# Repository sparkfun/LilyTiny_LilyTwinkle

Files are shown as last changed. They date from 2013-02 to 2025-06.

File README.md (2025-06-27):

LilyTiny / LilyTwinkle
======================

[LilyTiny / LilyTwinkle  
*LilyTiny (DEV-10899)*](https://www.sparkfun.com/products/10899) / [*LilyTwinkle (DEV-11364)*](https://www.sparkfun.com/products/11364)

LilyTiny and LilyTwinkle are ATtiny85-based development boards for eTextiles applications. Due to the small size of the board and hardware limitations of the processor, they do not have a bootloader like a conventional LilyPad Arduino compatible does. Instead, six pads are available in the center of the back side of the board, allowing it to be reprogrammed with a standard AVR ISP programmer simply by inserting male headers into the end of the programming cable and pressing them against the board.

In order to write new code for the ATtiny you will need to add support to the Arduino IDE. Please refer to the High-Low Tech group at MIT for a great tutorial on doing this: [http://hlt.media.mit.edu/?p=1695](http://hlt.media.mit.edu/?p=1695)

Repository Contents
-------------------

* **/Firmware** - Separate firmware files for the LilyTiny and the LilyTwinkle.
* **/Fritzing** - Fritzing Example wiring images
* **/Hardware** - All hardware files for both the LilyTiny *and* the LilyTwinkle (they are identical boards). For simplicity's sake, the hardware files are named *LilyTiny*.
* **/Production** - Test bed files and production panel files

Documentation
--------------

* Getting Started Tutorials
  * **[LDK Experiment 6: Microcontroller Circuits](https://learn.sparkfun.com/tutorials/ldk-experiment-6-microcontroller-circuits)**
  * **[Using the LilyPad LilyTwinkle board](https://www.sparkfun.com/tutorials/390)**
* Project Tutorials
  * **[Twinkle Zodiac Constellation](https://learn.sparkfun.com/tutorials/twinkle-zodiac-constellation)**
  * **[Night Sky Halloween Costume](https://learn.sparkfun.com/tutorials/night-sky-halloween-costume)**
  * **[Firefly Jar Assembly Guide](https://learn.sparkfun.com/tutorials/firefly-jar-assembly-guide)** 
  * **[Soft Circuits: LED Feelings Pizza](https://learn.sparkfun.com/tutorials/soft-circuits-led-feelings-pizza)**
  * **[Twinkling Trick or Treat Bag](https://learn.sparkfun.com/tutorials/twinkling-trick-or-treat-bag)**
  * **[Light Up Pennant with E-Textiles](https://learn.sparkfun.com/tutorials/light-up-pennant-with-e-textiles)**
  * **[LilyTiny Plush Monster](https://learn.sparkfun.com/tutorials/lilytiny-plush-monster)**
  * **[Twinkling Fairy Wings](https://www.sparkfun.com/tutorials/396)**
* **[Tiny AVR Programmer Hookup Guide](https://learn.sparkfun.com/tutorials/tiny-avr-programmer-hookup-guide)** - Hookup guide to reprogram an ATtiny85.
* **[Re-Programming the LilyTiny / LilyTwinkle](https://learn.sparkfun.com/tutorials/re-programming-the-lilytiny--lilytwinkle)** - Tutorial to reprogram the LilyTiny or LilyTwinkle.
* **[Quick Reference Guide for ATTiny85](https://learn.sparkfun.com/resources/96)** 

License Information
-------------------
The hardware is released under [Creative Commons ShareAlike 4.0 International](https://creativecommons.org/licenses/by-sa/4.0/).
The code is beerware; if you see me (or any other SparkFun employee) at the local, and you've found our code helpful, please buy us a round!

Distributed as-is; no warranty is given.

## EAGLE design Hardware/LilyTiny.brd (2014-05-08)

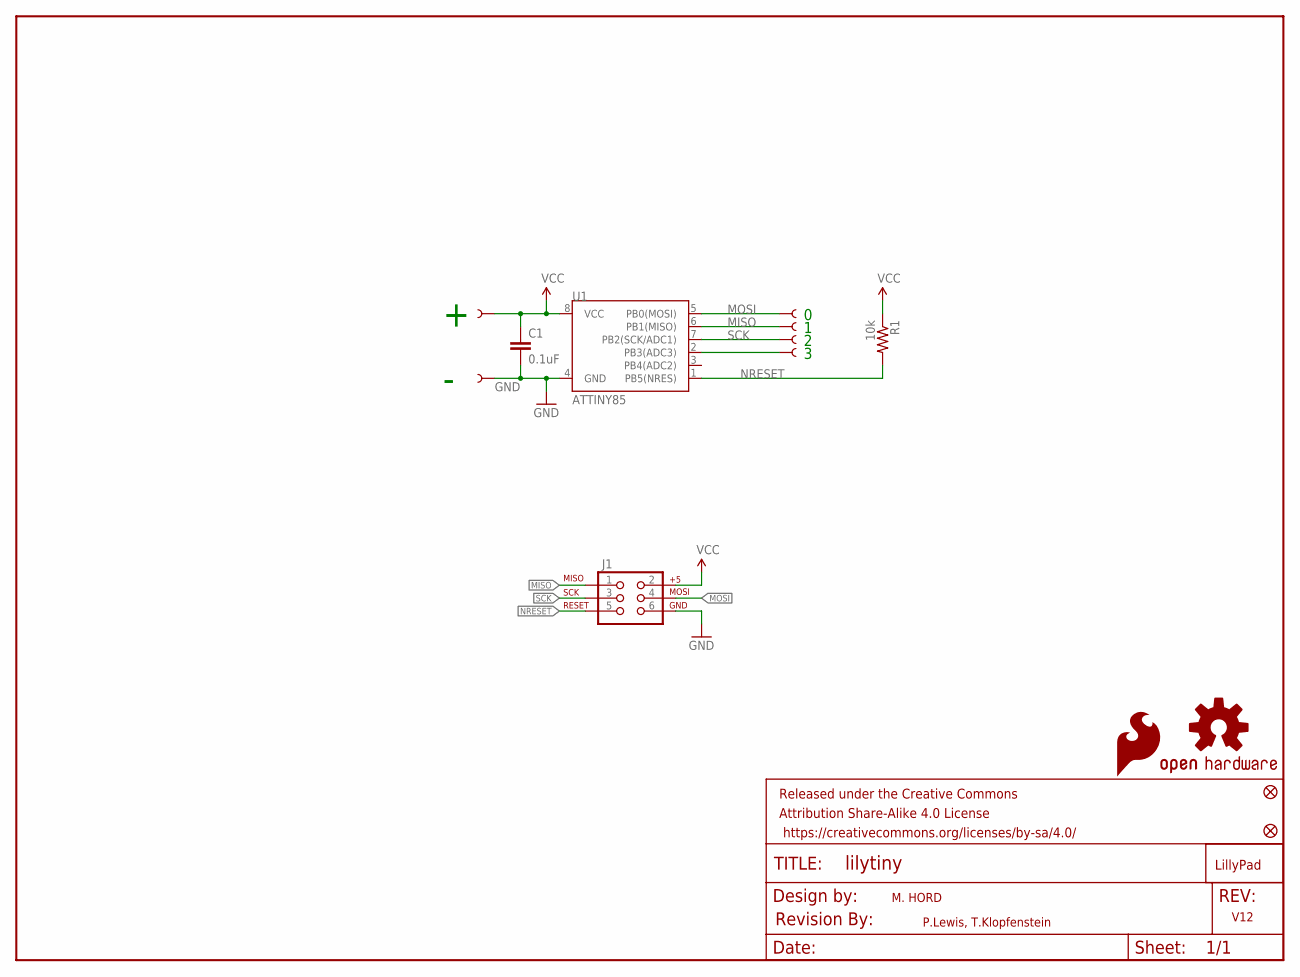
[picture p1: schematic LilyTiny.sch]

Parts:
C1: 0.1uF; 0603-CAP
FID1, FID2: FIDUCIAL1X2; FIDUCIAL-1X2
FRAME2: FRAME-LETTER; CREATIVE_COMMONS
J1: AVR_SPI_PRG_6TESTPOINTS; 2X3_TEST_POINTS
LOGO1: OSHW-LOGOS; OSHW-LOGO-S
LOGO2: SFE_LOGO_FLAME.1_INCH; SFE_LOGO_FLAME_.1
R1: 10k; 0603-RES
U1: ATTINY85; SO08-EIAJ
U$1: REVISION
U$2, U$3, U$4, U$5, U$6, U$7: SEWTAP6; PETAL-SMALL-2SIDE
U$8: LOGO-LPL; LOGO-L

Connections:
GND: C1.2, J1.6, U1.4 (GND), U$2.1
MISO: J1.1, U1.6 (PB1(MISO)), U$3.1
MOSI: J1.4, U1.5 (PB0(MOSI)), U$7.1
unnamed: U1.2 (PB3(ADC3)), U$6.1
NRESET: J1.5, R1.2, U1.1 (PB5(NRES))
SCK: J1.3, U1.7 (PB2(SCK/ADC1)), U$4.1
VCC: C1.1, J1.2, R1.1, U1.8 (VCC), U$5.1

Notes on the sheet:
M. HORD
P.Lewis, T.Klopfenstein
V12

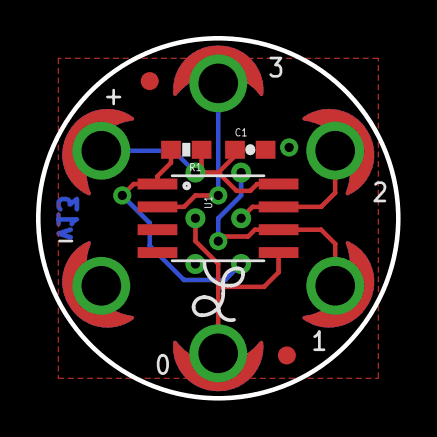
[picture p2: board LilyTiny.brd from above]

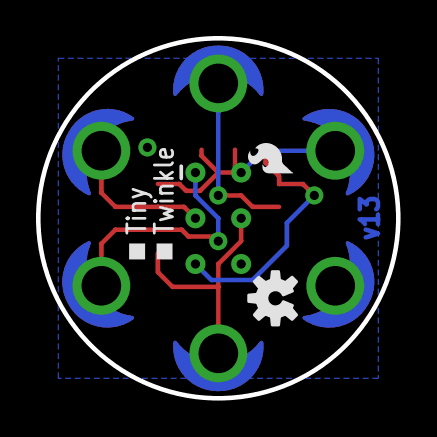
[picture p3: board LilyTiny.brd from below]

Board: 2 copper layers, 20.0 x 20.0 mm, 17 parts (3 on the bottom side), 7 nets.

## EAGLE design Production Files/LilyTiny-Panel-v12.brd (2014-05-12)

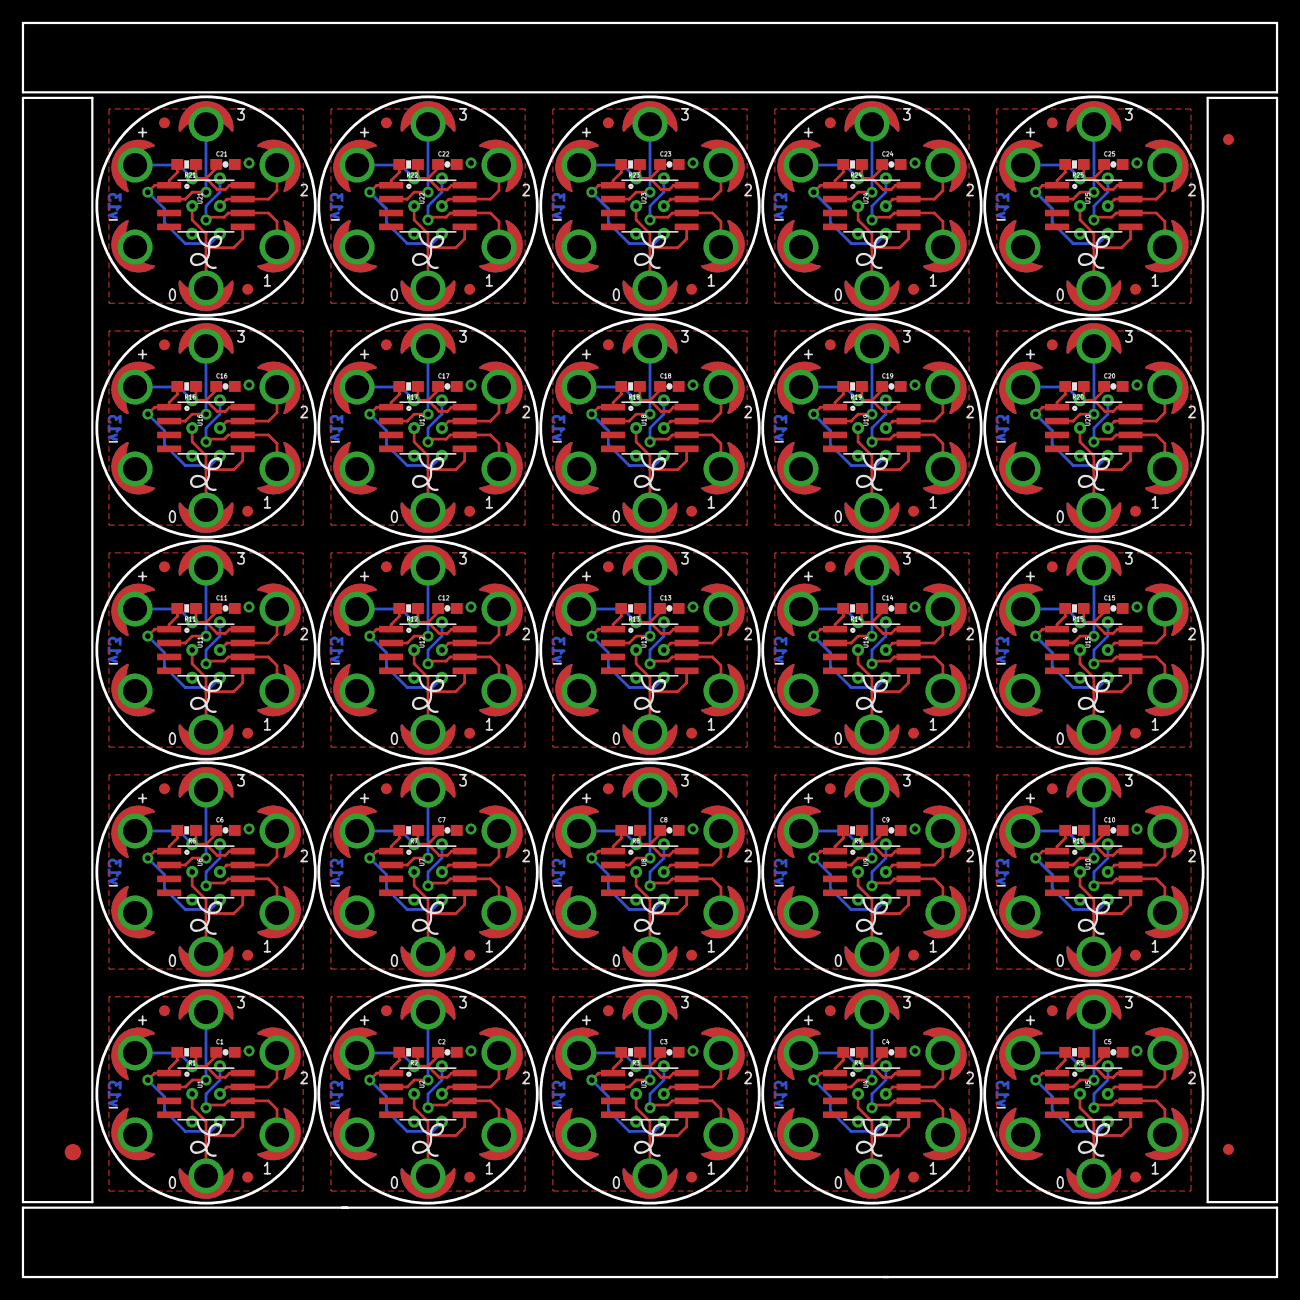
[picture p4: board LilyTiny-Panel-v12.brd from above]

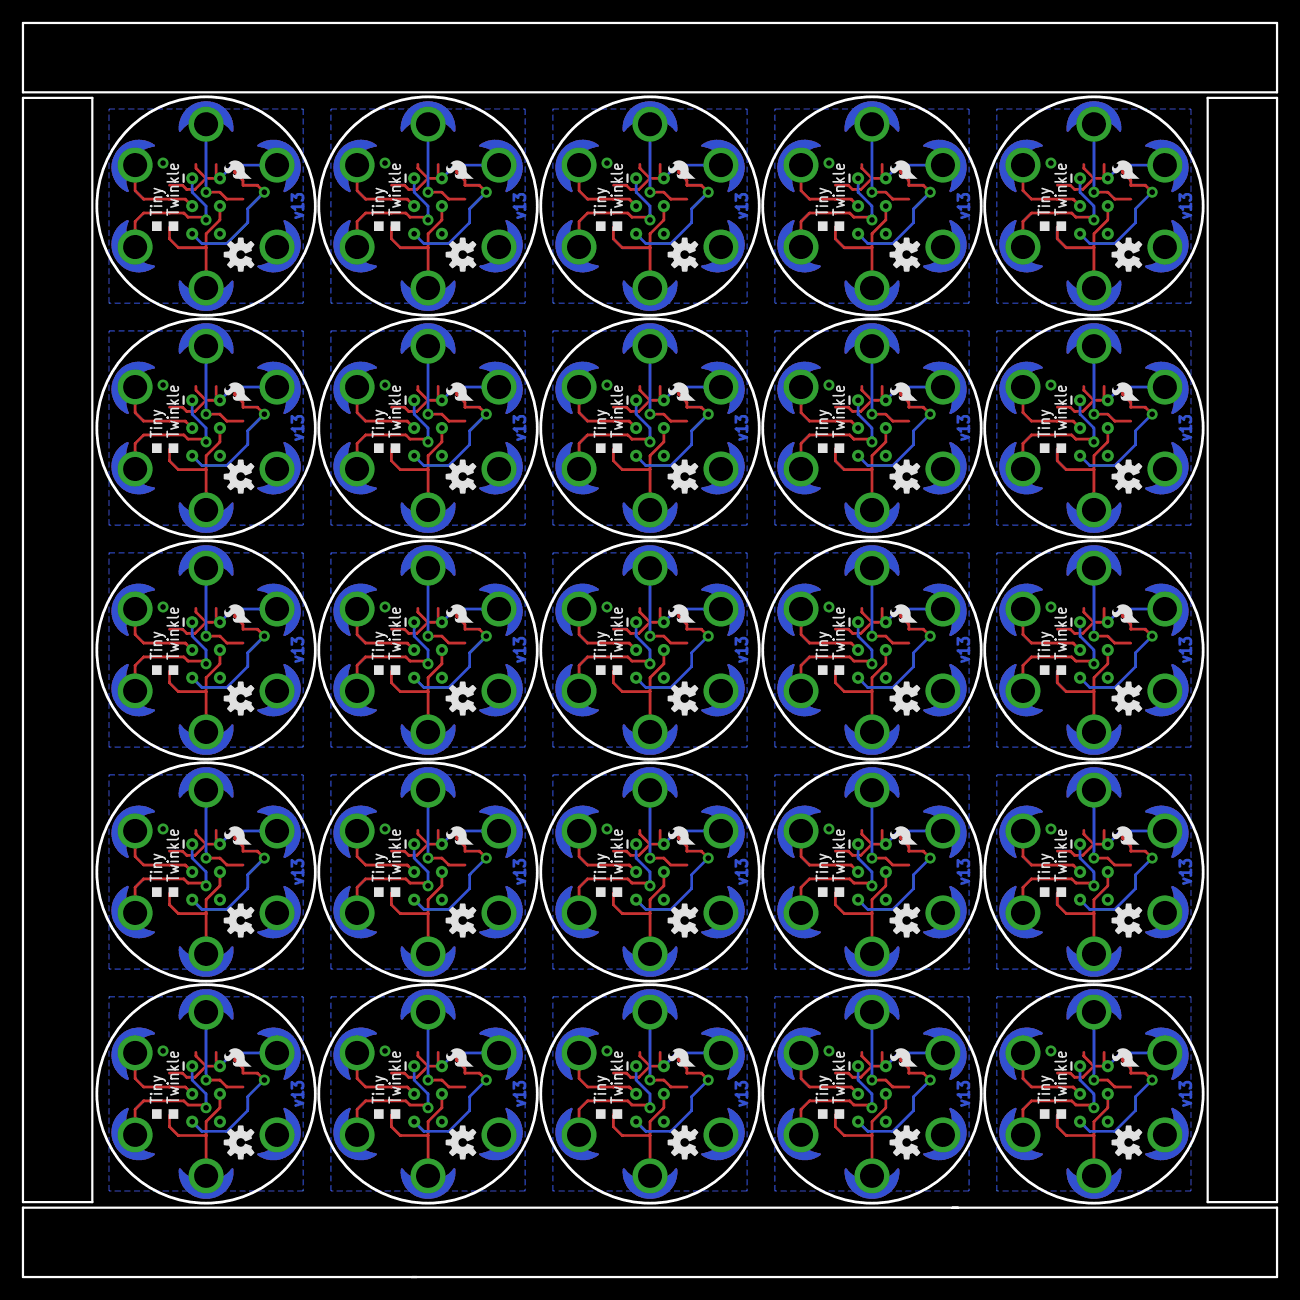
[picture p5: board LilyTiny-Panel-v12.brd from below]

Board: 2 copper layers, 114.8 x 114.8 mm, 378 parts (75 on the bottom side), 175 nets.

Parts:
C1, C2, C3, C4, C5, C6, C7, C8, C9, C10, C11, C12, C13, C14, C15, C16, C17, C18, C19, C20, C21, C22, C23, C24, C25: 0.1uF; 0603-CAP
E$1: FIDUCIAL-1.5X3
E$4, E$6: FIDUCIAL-1X2
FID1, FID2, FID3, FID4, FID5, FID6, FID7, FID8, FID9, FID10, FID11, FID12, FID13, FID14, FID15, FID16, FID17, FID18, FID19, FID20, FID21, FID22, FID23, FID24, FID25, FID26, FID27, FID28, FID29, FID30, FID31, FID32, FID33, FID34, FID35, FID36, FID37, FID38, FID39, FID40, FID41, FID42, FID43, FID44, FID45, FID46, FID47, FID48, FID49, FID50: FIDUCIAL1X2; FIDUCIAL-1X2
J1, J2, J3, J4, J5, J6, J7, J8, J9, J10, J11, J12, J13, J14, J15, J16, J17, J18, J19, J20, J21, J22, J23, J24, J25: 2X3_TEST_POINTS
LOGO1, LOGO3, LOGO5, LOGO7, LOGO9, LOGO11, LOGO13, LOGO15, LOGO17, LOGO19, LOGO21, LOGO23, LOGO25, LOGO27, LOGO29, LOGO31, LOGO33, LOGO35, LOGO37, LOGO39, LOGO41, LOGO43, LOGO45, LOGO47, LOGO49: OSHW-LOGOS; OSHW-LOGO-S
LOGO2, LOGO4, LOGO6, LOGO8, LOGO10, LOGO12, LOGO14, LOGO16, LOGO18, LOGO20, LOGO22, LOGO24, LOGO26, LOGO28, LOGO30, LOGO32, LOGO34, LOGO36, LOGO38, LOGO40, LOGO42, LOGO44, LOGO46, LOGO48, LOGO50: SFE_LOGO_FLAME.1_INCH; SFE_LOGO_FLAME_.1
R1, R2, R3, R4, R5, R6, R7, R8, R9, R10, R11, R12, R13, R14, R15, R16, R17, R18, R19, R20, R21, R22, R23, R24, R25: 10k; 0603-RES
U1, U2, U3, U4, U5, U6, U7, U8, U9, U10, U11, U12, U13, U14, U15, U16, U17, U18, U19, U20, U21, U22, U23, U24, U25: ATTINY85; SO08-EIAJ
U$1, U$2, U$3, U$4, U$5, U$6, U$7, U$9, U$10, U$11, U$12, U$13, U$15, U$16, U$17, U$18, U$19, U$20, U$22, U$23, U$24, U$25, U$26, U$27, U$29, U$30, U$31, U$32, U$33, U$34, U$36, U$37, U$38, U$39, U$40, U$41, U$43, U$44, U$45, U$46, U$47, U$48, U$50, U$51, U$52, U$53, U$54, U$55, U$57, U$58, U$59, U$60, U$61, U$62, U$64, U$65, U$66, U$67, U$68, U$69, U$71, U$72, U$73, U$74, U$75, U$76, U$78, U$79, U$80, U$81, U$82, U$83, U$85, U$86, U$87, U$88, U$89, U$90, U$92, U$93, U$94, U$95, U$96, U$97, U$99, U$100, U$101, U$102, U$103, U$104, U$106, U$107, U$108, U$109, U$110, U$111, U$113, U$114, U$115, U$116, U$117, U$118, U$120, U$121, U$122, U$123, U$124, U$125, U$127, U$128, U$129, U$130, U$131, U$132, U$134, U$135, U$136, U$137, U$138, U$139, U$141, U$142, U$143, U$144, U$145, U$146, U$148, U$149, U$150, U$151, U$152, U$153, U$155, U$156, U$157, U$158, U$159, U$160, U$162, U$163, U$164, U$165, U$166, U$167, U$169, U$170, U$171, U$172, U$173, U$174: SEWTAP6; PETAL-SMALL-2SIDE
U$8, U$14, U$21, U$28, U$35, U$42, U$49, U$56, U$63, U$70, U$77, U$84, U$91, U$98, U$105, U$112, U$119, U$126, U$133, U$140, U$147, U$154, U$161, U$168, U$175: LOGO-LPL; LOGO-L

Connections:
GND: C1.2, J1.6, U1.4, U$2.1
GND1: C2.2, J2.6, U2.4, U$1.1
GND2: C3.2, J3.6, U3.4, U$15.1
GND3: C4.2, J4.6, U4.4, U$22.1
GND4: C5.2, J5.6, U5.4, U$29.1
GND5: C6.2, J6.6, U6.4, U$36.1
GND6: C7.2, J7.6, U7.4, U$43.1
GND7: C8.2, J8.6, U8.4, U$50.1
GND8: C9.2, J9.6, U9.4, U$57.1
GND9: C10.2, J10.6, U10.4, U$64.1
GND10: C11.2, J11.6, U11.4, U$71.1
GND11: C12.2, J12.6, U12.4, U$78.1
GND12: C13.2, J13.6, U13.4, U$85.1
GND13: C14.2, J14.6, U14.4, U$92.1
GND14: C15.2, J15.6, U15.4, U$99.1
GND15: C16.2, J16.6, U16.4, U$106.1
GND16: C17.2, J17.6, U17.4, U$113.1
GND17: C18.2, J18.6, U18.4, U$120.1
GND18: C19.2, J19.6, U19.4, U$127.1
GND19: C20.2, J20.6, U20.4, U$134.1
GND20: C21.2, J21.6, U21.4, U$141.1
GND21: C22.2, J22.6, U22.4, U$148.1
GND22: C23.2, J23.6, U23.4, U$155.1
GND23: C24.2, J24.6, U24.4, U$162.1
GND24: C25.2, J25.6, U25.4, U$169.1
MISO: J1.1, U1.6, U$3.1
MISO1: J2.1, U2.6, U$9.1
MISO2: J3.1, U3.6, U$16.1
MISO3: J4.1, U4.6, U$23.1
MISO4: J5.1, U5.6, U$30.1
MISO5: J6.1, U6.6, U$37.1
MISO6: J7.1, U7.6, U$44.1
MISO7: J8.1, U8.6, U$51.1
MISO8: J9.1, U9.6, U$58.1
MISO9: J10.1, U10.6, U$65.1
MISO10: J11.1, U11.6, U$72.1
MISO11: J12.1, U12.6, U$79.1
MISO12: J13.1, U13.6, U$86.1
MISO13: J14.1, U14.6, U$93.1
MISO14: J15.1, U15.6, U$100.1
MISO15: J16.1, U16.6, U$107.1
MISO16: J17.1, U17.6, U$114.1
MISO17: J18.1, U18.6, U$121.1
MISO18: J19.1, U19.6, U$128.1
MISO19: J20.1, U20.6, U$135.1
MISO20: J21.1, U21.6, U$142.1
MISO21: J22.1, U22.6, U$149.1
MISO22: J23.1, U23.6, U$156.1
MISO23: J24.1, U24.6, U$163.1
MISO24: J25.1, U25.6, U$170.1
MOSI: J1.4, U1.5, U$7.1
MOSI1: J2.4, U2.5, U$13.1
MOSI2: J3.4, U3.5, U$20.1
MOSI3: J4.4, U4.5, U$27.1
MOSI4: J5.4, U5.5, U$34.1
MOSI5: J6.4, U6.5, U$41.1
MOSI6: J7.4, U7.5, U$48.1
MOSI7: J8.4, U8.5, U$55.1
MOSI8: J9.4, U9.5, U$62.1
MOSI9: J10.4, U10.5, U$69.1
MOSI10: J11.4, U11.5, U$76.1
MOSI11: J12.4, U12.5, U$83.1
MOSI12: J13.4, U13.5, U$90.1
MOSI13: J14.4, U14.5, U$97.1
MOSI14: J15.4, U15.5, U$104.1
MOSI15: J16.4, U16.5, U$111.1
MOSI16: J17.4, U17.5, U$118.1
MOSI17: J18.4, U18.5, U$125.1
MOSI18: J19.4, U19.5, U$132.1
MOSI19: J20.4, U20.5, U$139.1
MOSI20: J21.4, U21.5, U$146.1
MOSI21: J22.4, U22.5, U$153.1
MOSI22: J23.4, U23.5, U$160.1
MOSI23: J24.4, U24.5, U$167.1
MOSI24: J25.4, U25.5, U$174.1
unnamed: U2.2, U$12.1
unnamed: U3.2, U$19.1
unnamed: U4.2, U$26.1
unnamed: U5.2, U$33.1
unnamed: U1.2, U$6.1
unnamed: U6.2, U$40.1
unnamed: U7.2, U$47.1
unnamed: U8.2, U$54.1
unnamed: U9.2, U$61.1
unnamed: U10.2, U$68.1
unnamed: U11.2, U$75.1
unnamed: U12.2, U$82.1
unnamed: U13.2, U$89.1
unnamed: U14.2, U$96.1
unnamed: U15.2, U$103.1
unnamed: U16.2, U$110.1
unnamed: U17.2, U$117.1
unnamed: U18.2, U$124.1
unnamed: U19.2, U$131.1
unnamed: U20.2, U$138.1
unnamed: U21.2, U$145.1
unnamed: U22.2, U$152.1
unnamed: U23.2, U$159.1
unnamed: U24.2, U$166.1
unnamed: U25.2, U$173.1
NRESET: J1.5, R1.2, U1.1
NRESET1: J2.5, R2.2, U2.1
NRESET2: J3.5, R3.2, U3.1
NRESET3: J4.5, R4.2, U4.1
NRESET4: J5.5, R5.2, U5.1
NRESET5: J6.5, R6.2, U6.1
NRESET6: J7.5, R7.2, U7.1
NRESET7: J8.5, R8.2, U8.1
NRESET8: J9.5, R9.2, U9.1
NRESET9: J10.5, R10.2, U10.1
NRESET10: J11.5, R11.2, U11.1
NRESET11: J12.5, R12.2, U12.1
NRESET12: J13.5, R13.2, U13.1
NRESET13: J14.5, R14.2, U14.1
NRESET14: J15.5, R15.2, U15.1
NRESET15: J16.5, R16.2, U16.1
NRESET16: J17.5, R17.2, U17.1
NRESET17: J18.5, R18.2, U18.1
NRESET18: J19.5, R19.2, U19.1
NRESET19: J20.5, R20.2, U20.1
NRESET20: J21.5, R21.2, U21.1
NRESET21: J22.5, R22.2, U22.1
NRESET22: J23.5, R23.2, U23.1
NRESET23: J24.5, R24.2, U24.1
NRESET24: J25.5, R25.2, U25.1
SCK: J1.3, U1.7, U$4.1
SCK1: J2.3, U2.7, U$10.1
SCK2: J3.3, U3.7, U$17.1
SCK3: J4.3, U4.7, U$24.1
SCK4: J5.3, U5.7, U$31.1
SCK5: J6.3, U6.7, U$38.1
SCK6: J7.3, U7.7, U$45.1
SCK7: J8.3, U8.7, U$52.1
SCK8: J9.3, U9.7, U$59.1
SCK9: J10.3, U10.7, U$66.1
SCK10: J11.3, U11.7, U$73.1
SCK11: J12.3, U12.7, U$80.1
SCK12: J13.3, U13.7, U$87.1
SCK13: J14.3, U14.7, U$94.1
SCK14: J15.3, U15.7, U$101.1
SCK15: J16.3, U16.7, U$108.1
SCK16: J17.3, U17.7, U$115.1
SCK17: J18.3, U18.7, U$122.1
SCK18: J19.3, U19.7, U$129.1
SCK19: J20.3, U20.7, U$136.1
SCK20: J21.3, U21.7, U$143.1
SCK21: J22.3, U22.7, U$150.1
SCK22: J23.3, U23.7, U$157.1
SCK23: J24.3, U24.7, U$164.1
SCK24: J25.3, U25.7, U$171.1
VCC: C1.1, J1.2, R1.1, U1.8, U$5.1
VCC1: C2.1, J2.2, R2.1, U2.8, U$11.1
VCC2: C3.1, J3.2, R3.1, U3.8, U$18.1
VCC3: C4.1, J4.2, R4.1, U4.8, U$25.1
VCC4: C5.1, J5.2, R5.1, U5.8, U$32.1
VCC5: C6.1, J6.2, R6.1, U6.8, U$39.1
VCC6: C7.1, J7.2, R7.1, U7.8, U$46.1
VCC7: C8.1, J8.2, R8.1, U8.8, U$53.1
VCC8: C9.1, J9.2, R9.1, U9.8, U$60.1
VCC9: C10.1, J10.2, R10.1, U10.8, U$67.1
VCC10: C11.1, J11.2, R11.1, U11.8, U$74.1
VCC11: C12.1, J12.2, R12.1, U12.8, U$81.1
VCC12: C13.1, J13.2, R13.1, U13.8, U$88.1
VCC13: C14.1, J14.2, R14.1, U14.8, U$95.1
VCC14: C15.1, J15.2, R15.1, U15.8, U$102.1
VCC15: C16.1, J16.2, R16.1, U16.8, U$109.1
VCC16: C17.1, J17.2, R17.1, U17.8, U$116.1
VCC17: C18.1, J18.2, R18.1, U18.8, U$123.1
VCC18: C19.1, J19.2, R19.1, U19.8, U$130.1
VCC19: C20.1, J20.2, R20.1, U20.8, U$137.1
VCC20: C21.1, J21.2, R21.1, U21.8, U$144.1
VCC21: C22.1, J22.2, R22.1, U22.8, U$151.1
VCC22: C23.1, J23.2, R23.1, U23.8, U$158.1
VCC23: C24.1, J24.2, R24.1, U24.8, U$165.1
VCC24: C25.1, J25.2, R25.1, U25.8, U$172.1

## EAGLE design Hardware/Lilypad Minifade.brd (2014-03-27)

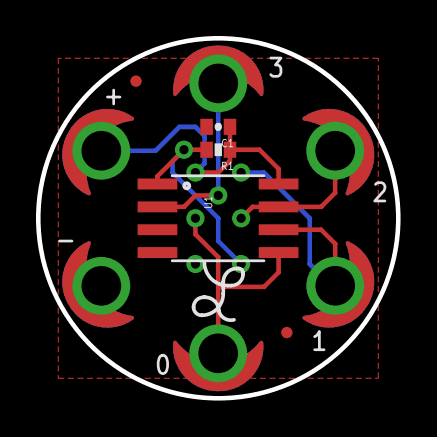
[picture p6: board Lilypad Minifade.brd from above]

Board: 2 copper layers, 20.0 x 20.0 mm, 13 parts (0 on the bottom side), 7 nets.

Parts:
C1: 0.1uF; 0402-CAP
JP1, JP2: FIDUCIALUFIDUCIAL; MICRO-FIDUCIAL
R1: 10k; 0402-RES
U1: ATTINY85; SO08-EIAJ
U$1: CREATIVE_COMMONS
U$2, U$3, U$4, U$5, U$6, U$7: SEWTAP6; PETAL-SMALL-2SIDE
U$8: LOGO-LPL; LOGO-L

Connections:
GND: C1.2, U1.4, U$2.1
unnamed: U1.5, U$7.1
unnamed: U1.6, U$3.1
unnamed: U1.7, U$4.1
unnamed: U1.2, U$6.1
NRESET: R1.2, U1.1
VCC: C1.1, R1.1, U1.8, U$5.1

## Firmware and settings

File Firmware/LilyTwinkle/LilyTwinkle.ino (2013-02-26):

// AVRDUDE fuse settings string:
// avrdude -p t85 -c avrispmkii -B 4 -P usb -U lfuse:w:0xe2:m -U hfuse:w:0xdf:m -U efuse:w:0xff:m
// By the time most users see this board, these settings will already 
//  have been applied. However, when programming from a blank ATTiny, it
//  is necessary to program the fuse bits to disable the divide-by-8
//  on the clock frequency.

#define LED0 0
#define LED1 1
#define LED2 2
#define LED3 3

#define FADEMIN   50   // FADEMIN and FADEMAX control the rate of fading. The wider
#define FADEMAX   55   //  the spread here, the greater the difference between
                       //  fastest fade and slowest fade. FADEMIN sets the lower
                       //  limit; the smaller that number gets, the faster the fade
                       //  will be allowed to be. 
#define FADEFALSE 25   // FADEFALSE and FADETRUE are a sort of dice-roll to decide
#define FADETRUE  30   //  whether an LED will be on for this cycle or not. Every
                       //  time an LED hits zero brightness, a random number between
                       //  0 and FADETRUE + 1 is created. If that number is greater
                       //  than FADEFALSE, the LED will go through a twinkle cycle.
                       //  If it's less than FADEFALSE, the code will still run as
                       //  though a twinkle is occuring, but the LED won't come on.
#define LIMITMIN  125  // LIMITMIN and LIMITMAX are the limits on the brightest the
#define LIMITMAX  255  //  LED can get.

long delayTime = 50;   // Sets the loop speed, in microseconds.
long startTime = 0;    // Counter, for tracking loop iterations.

byte onTime0 = 0;      // Time an LED should be on before turning off for PWM
byte onCounter0 = 0;   // How long the LED *has* been on for PWM
byte limit0 = 255;     // The point at which the LED's onCounter resets to 0
char dir0 = 1;         // Are we getting brighter (1), or dimmer (-1)?
boolean enable0 = true;// Results for the current "dice roll"
int fadeTimer0 = 10;   // How long should we PWM before increasing onTime?
int fadeCounter0 = 0;  // How long have we been PWMing since last onTime increase?

byte onTime1 = 0;
byte onCounter1 = 0;
byte limit1 = 255;
char dir1 = 1;
boolean enable1 = true;
int fadeTimer1 = 10;
int fadeCounter1 = 0;

byte onTime2 = 0;
byte onCounter2 = 0;
byte limit2 = 255;
char dir2 = 1;
boolean enable2 = true;
int fadeTimer2 = 10;
int fadeCounter2 = 0;

byte onTime3 = 0;
byte onCounter3 = 0;
byte limit3 = 255;
char dir3 = 1;
boolean enable3 = true;
int fadeTimer3 = 10;
int fadeCounter3 = 0;

void setup()  { 
  randomSeed(analogRead(3));
  pinMode(LED0, OUTPUT);
  pinMode(LED1, OUTPUT);
  pinMode(LED2, OUTPUT);
  pinMode(LED3, OUTPUT);
  startTime = micros();
} 

void loop()
{ 
  long currTime = micros();
  // This is a software PWM thing. We invoke this loop every 50us, at the fastest,
  //  although it may happen less often than that.
  if ( (currTime - startTime) > delayTime)
  {
    startTime = currTime;   // Record the last time we entered the loop.
  //  LED0 section-----------------------------------------------------------------
  //  Each of the four LEDx sections is exactly like the others, so I'll only
  //   comment the first one. The idea is pretty simple: on each pass through the
  //   loop, we increment two counters for each LED. One of them, onCounter, tracks
  //   whether the LED is on or off for PWM purposes. The other, fadeCounter, tracks
  //   wether it's time to increase (or decrease) the amount of time the LED will
  //   remain on for the next cycle, thereby increasing (or decreasing) the LEDs
  //   apparent brightness.
  
    // This if/else controls on/off of the LED:
    // enable is an override- some percentage of the time, we don't want the LED
    //  to be on at all; otherwise, the LEDs will be on too much.
    if (!enable0)                   digitalWrite(LED0, LOW);
    // while onCounter < onTime, the LED should be on. This is the short loop,
    //  which effectively PWMs the LED.
    else if (onCounter0 > onTime0) digitalWrite(LED0, LOW);
    else                           digitalWrite(LED0, HIGH);
    onCounter0++;    // Advance the PWM counter. The number of times we loiter on
                     //  a single brightness value before increasing or decreasing
                     //  it is determined by the fadeCounter/fadeTimer relationship
    fadeCounter0++;  // Advance the fade counter. This value controls the rate at
                     //  which the fade occurs- the higher the value of fadeTimer,
                     //  the slower the twinkle. After each fade cycle, we pick a
                     //  new, random-ish value for fadeTimer, with limits set by
                     //  FADEMIN and FADEMAX above.
    if (fadeCounter0 == fadeTimer0)
    {
      fadeCounter0 = 0;  // Reset the fade counter for the next fade cycle.
      onTime0 += dir0;   // Increase or decrease onTime, depending on whether we're
                         //  increasing or decreasing brightness.
      
      // Change from increasing brightness to decreasing brightness, or vice versa.
      if ((onTime0 == limit0) || (onTime0 == 0)) dir0 *= -1;
      // When we hit bottom, but before we start counting back up, randomize our
      //  variables for the next time around.
      if ((onTime0 == 0) && (dir0 = 1))
      {
        // limit is the point at which the LED stops getting brighter and starts to
        //  dim again.
        limit0 =     random(LIMITMIN,LIMITMAX);
        // fadeTimer controls how fast the fading occurs. The lower it is, the
        //  faster the fade. FADEMIN and FADEMAX are set to a nice value.
        fadeTimer0 = random(FADEMIN,FADEMAX);
        // enable is a sort of dice-roll for whether the LED will be on or not for
        //  the next cycle it runs through. The probability runs something like
        //  FADEFALSE/(FADETRUE+1); by default, that's 25/31 or about 80% of the
        //  rolls should be negative. We want to force an enable if more than a
        //  couple of disables have passed.
        enable0 =  random(0,FADETRUE+1) >= FADEFALSE;
      }
    }
     
  //  LED1 section-----------------------------------------------------------------
    if (!enable1)                   digitalWrite(LED1, LOW);
    else if (onCounter1 > onTime1) digitalWrite(LED1, LOW);
    else                           digitalWrite(LED1, HIGH);
    onCounter1++;
    fadeCounter1++;
    if (fadeCounter1 == fadeTimer1)
    {
      fadeCounter1 = 0;
      onTime1 += dir1;
      if ((onTime1 == limit1) || (onTime1 == 0)) dir1 *= -1;
      if ((onTime1 == 0) && (dir1 = 1))
      {
        limit1 =     random(LIMITMIN,LIMITMAX);
        fadeTimer1 = random(FADEMIN,FADEMAX);
        enable1 =    random(0,FADETRUE+1) >= FADEFALSE;
      }
    }

  //  LED2 section-----------------------------------------------------------------
    if (!enable2)                   digitalWrite(LED2, LOW);
    else if (onCounter2 > onTime2) digitalWrite(LED2, LOW);
    else                           digitalWrite(LED2, HIGH);
    onCounter2++;
    fadeCounter2++;
    if (fadeCounter2 == fadeTimer2)
    {
      fadeCounter2 = 0;
      onTime2 += dir2;
      if ((onTime2 == limit2) || (onTime2 == 0)) dir2 *= -1;
      if ((onTime2 == 0) && (dir2 = 1))
      {
        limit2 =     random(LIMITMIN,LIMITMAX);
        fadeTimer2 = random(FADEMIN,FADEMAX);
        enable2 =    random(0,FADETRUE+1) >= FADEFALSE;
      }
    }
  
  //  LED3 section-----------------------------------------------------------------
    if (!enable3)                   digitalWrite(LED3, LOW);
    else if (onCounter3 > onTime3) digitalWrite(LED3, LOW);
    else                           digitalWrite(LED3, HIGH);
    onCounter3++;
    fadeCounter3++;
    if (fadeCounter3 == fadeTimer3)
    {
      fadeCounter3 = 0;
      onTime3 += dir3;
      if ((onTime3 == limit3) || (onTime3 == 0)) dir3 *= -1;
      if ((onTime3 == 0) && (dir3 = 1))
      {
        limit3 =     random(LIMITMIN,LIMITMAX);
        fadeTimer3 = random(FADEMIN,FADEMAX);
        enable3 =    random(0,FADETRUE+1) >= FADEFALSE;
      }
    }
  }
}

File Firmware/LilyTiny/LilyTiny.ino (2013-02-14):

/******************************************************************************
  LilyTiny (ATtiny85, internal 8 MHz clock)
  Emily Lovell
 
  Controls the behavior of up to four LEDs, depending on pin:
    Pin 0: fades in and out
    Pin 1: heartbeat
    Pin 2: blinks on and off
    Pin 3: twinkles randomly
    
 AVRDUDE fuse settings string:
 avrdude -p t85 -c avrispmkii -B 4 -P usb -U lfuse:w:0xe2:m -U hfuse:w:0xdf:m -U efuse:w:0xff:m
 By the time most users see this board, these settings will already 
  have been applied. However, when programming from a blank ATTiny, it
  is necessary to program the fuse bits to disable the divide-by-8
  on the clock frequency.
******************************************************************************/

// Constant definitions
#define maxBrightness 255.0

#define maxTimeOn 9999 
#define blinkTime 125 

// Variables and constants for fading pin. Needs to be a pin with PWM hardware
//  available; on the Tiny85 that's pin 0 and pin 1 only.
#define fadePin 	0  			// Redefine the pin name to something
								//  application specific.
int fadeDirection 	= 1; 		// 1 is brighter, -1 is dimmer
int fadeStep 		= 1; 
int fadeBrightness 	= 1; 

// Variables and constants for fading pin. Needs to be a hardware PWM pin; on
//  Tiny85 that's pin 0 and pin 1 only.
#define HEARTPIN	1 			// Redefine the pin name to something
								//  application specific.
int heartStage = 0;
float heartBrightness = 0;
float heartCounter = 0;

// variables for blink pin (pin 2)
int blinkPin = 2; 
int blinkDelay = blinkTime;
int blinkState = false;

// variables for twinkle pin (pin 3)
int twinklePin = 3; 
int timeOn = 0;
float currentBrightness = 0;
int targetBrightness = 0;
float timeToBright = 0;
float stepToBright = 0;


void setup()
{
  pinMode(twinklePin, OUTPUT);
  startOver();
  pinMode(blinkPin, OUTPUT);
}

void loop()
{
  // calculate brightness for twinkle pin (determined 
  // by how much time the LED is on vs. off) 
  timeOn = calcTimeOn(currentBrightness);
  digitalWrite(twinklePin, HIGH);
  delayMicroseconds(timeOn + 1);
  digitalWrite(twinklePin, LOW);
  delayMicroseconds(maxTimeOn - timeOn);

  // recalculate brightness for twinkle pin
  currentBrightness += stepToBright;
  timeToBright--;
  if(timeToBright == 0)
    startOver();
 
  // calculate brightness for heartbeat pin (by cycling 
  // through phases of pulse pattern)
  heartCounter++;
  if (heartCounter > 144) {
    heartStage = (heartStage + 1) % 4;
    heartCounter = 0;
  }
  else {
    switch(heartStage) {
      case 0:
        analogWrite(HEARTPIN, heartBrightness);
        heartCounter += 144/12.0;
        heartBrightness += 255/12.0;
        if (heartBrightness > 255)
          heartBrightness = 255;
        break;
      case 1:
        analogWrite(HEARTPIN, heartBrightness);
        heartCounter += 144/24.0;
        heartBrightness -= 255/24.0;
        if (heartBrightness < 0)
          heartBrightness = 0;
        break;
      case 2:
        analogWrite(HEARTPIN, heartBrightness);
        heartCounter += 144/12.0;
        heartBrightness += 255/12.0;
        if (heartBrightness > 255)
          heartBrightness = 255;
        break;
      case 3:
        analogWrite(HEARTPIN, heartBrightness);
        heartCounter += 144/72.0;
        heartBrightness -= 255/72.0;
        if (heartBrightness < 0)
          heartBrightness = 0;
        break;
    }
  }
    
 
  // drive blink pin high or low, depending on how much time has passed
  blinkDelay--;
  if (blinkDelay == 0) {
    blinkDelay = blinkTime;
    blinkState = !blinkState;
    digitalWrite(blinkPin, blinkState);
  }  
  
  // increase/decrease brightness of fade pin in steady incremental steps
  analogWrite(fadePin, fadeBrightness);
  fadeBrightness += fadeStep * fadeDirection;
  if (fadeBrightness >= 255) {
    fadeBrightness = 255;
    fadeDirection = -1;
  }
  if (fadeBrightness <= 0) {
    fadeBrightness = 0;
    fadeDirection = 1; 
  }
}

// calculate ratio of time LED is on/off to acheive particular brightness
int calcTimeOn(int desiredBrightness) {
  return desiredBrightness / maxBrightness * maxTimeOn;
}


// restart a new twinkle 
void startOver(){
  if (random(0, 1) == 1)
    targetBrightness = currentBrightness + random(100, 200);
  else
    targetBrightness = currentBrightness - random(100, 200);
  if (targetBrightness < 0)
    targetBrightness = maxBrightness + targetBrightness;
  targetBrightness %= (int)maxBrightness;
  timeToBright = random(10, 30); 
  stepToBright = (targetBrightness - currentBrightness) / timeToBright;
}

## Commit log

2012-11-21 Initial commit.
    This is v12 of the board and the shipping firmware as of 21 Nov 2012.
    Going forward changes to board files or firmware will be done through
    Git; older changes persist in SparkFun servers only.
    [LilyTiny-Panel.brd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]
2013-02-14 Added fuse bit strings for AVRDUDE in the code files.
2013-02-26 Added an all-LED twinkle at boot time.
2013-07-31 Adding Firmware tick marks
    After programming firmware, our techs will put a small mark on the
    appropriate box. This is to help ensure that we don't mix the two
    different products up in SFE inventory. A big thanks to meatball for
    instigating this change!!
    [LilyTiny.brd]
2013-07-31 Moved components to 0603 package size
    [LilyTiny.brd, LilyTiny.sch]
2013-07-31 Moved to 0603 components, added OSHW logo
    -moved R1 and C1 a bit to fit in 0603 packages. Had to re-route some
    traces.
    -Added OSHW.
    -Updated Frame.
    -added version to both sch and brd
    [LilyTiny.brd, LilyTiny.sch]
2014-02-19 Updating production file organization
    [LilyTiny-Panel.brd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]
2014-02-19 Updating files to more clearly differentiate between Tiny/Twinkle
    [LilyTiny.brd, LilyTiny.sch]
2014-02-19 Correcting hardware files to current pcbs we are selling
    [LilyTiny.sch, Lilypad Minifade.brd, Lilypad Minifade.sch]
2014-03-26 Fixing silk errors from protos
    [LilyTiny.brd]
2014-03-27 Fixing merge conflicts
    [LilyTiny.brd, LilyTiny.sch]
2014-03-27 Fixing merge conflicts numero dos.
    Getting files ready for production runs.
    [LilyTiny.brd, LilyTiny.sch, Lilypad Minifade.sch]
2014-04-02 Added regular fid to board. Deleted old gerbs
    [LilyTiny-Panel.brd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]
2014-04-02 created panel v12
    [LilyTiny-Panel-v12.brd]
2014-05-07 Fixed bStop on programming vias
    There is bStop added to expose the bottom side of the programming vias.
    It used to be a circle, which did not expose 100% of the via - it still
    contained a little "dot" of mask covering up the center of the vias.
    This has made it difficult (if not impossible) to program. On this
    commit, I added a circle drawn with the polygon tool to the bStop on all
    6 vias to expose 100% of the vias.
    [LilyTiny.brd]
2014-05-08 Switched programming lines from vias to device
    -Used AVR_SPI_PRG_6.dev with the new "TEST_POINTS" package (which
    include the necessary stop mask).
    -Centered symbols in schematic.
    [LilyTiny.brd, LilyTiny.sch]
2014-05-12 re-did panel v12
    [LilyTiny-Panel-v12.brd]
2014-06-12 Deleting old pdf of schematic

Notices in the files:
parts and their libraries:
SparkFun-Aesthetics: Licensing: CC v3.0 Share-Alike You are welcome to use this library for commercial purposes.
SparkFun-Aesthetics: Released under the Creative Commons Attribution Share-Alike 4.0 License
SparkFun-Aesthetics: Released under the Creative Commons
